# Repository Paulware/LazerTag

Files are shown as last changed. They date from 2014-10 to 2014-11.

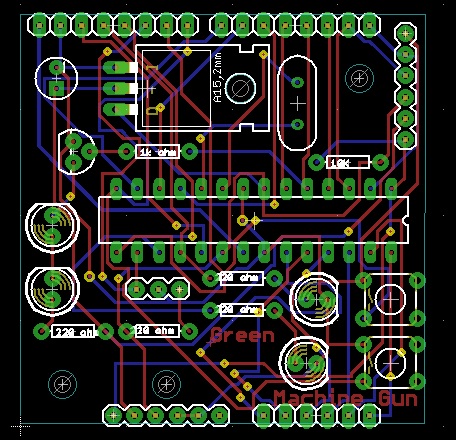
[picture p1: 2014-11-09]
ShieldHardware/IRRxTx.jpg

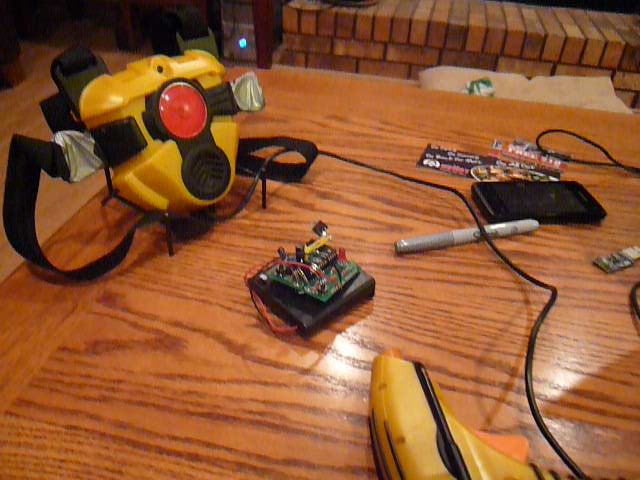
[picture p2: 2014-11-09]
LazerTag/P1040091.JPG

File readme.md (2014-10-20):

<H3>Hardware</H3>
<ul>
<li> Arduino Shield with IR Transmit and receive</li>
<ul>
<li>Fritzing Diagrama</li>
<li>Eagle schematic and board</li>
<li>Gerber .zip file (Iteadstudio.com) can create pcb</li>
</ul>
</ul>
<H3>Software</H3>
<ul>
<li>LazerTag.ino sketch to send and receive pulses</li>
<li>libraries</li>
<ul>
<li>IR - Basic IR Sampling library</li>
<li>IRLazer - Lazer tab receive and transmit</li>
</ul>
</ul>
<hr>
Future:
  Add :
    IR "grenades"
    Capture the ir "flag"

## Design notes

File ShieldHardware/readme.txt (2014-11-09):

11/3/2014
    Red LED should be marked because infra-red emitters also look like leds.
    IR Tx leds should be rotated 90 degrees so they can be bent without shorting
    3V regulator LD33V has incorrect part in schematic.  Its a sparkfun part.
    Pinout was incorrectly for LM7805 regulator 
    Ready for reorder (not urgent)
    To assemble, shift LD part one pin, unused pin goes to first pin(VCC)
    
11/6/2014
    16 mhz clock and 10k resistor moved to top of pcb so that the unit 
    can be glued to a flat surface.  Added standoff holes .
    
11/7/2014
    Added 8 and 6 pin headers in case this could be used like a DIY Arduino.  Moved
    standoffs more to the corner.

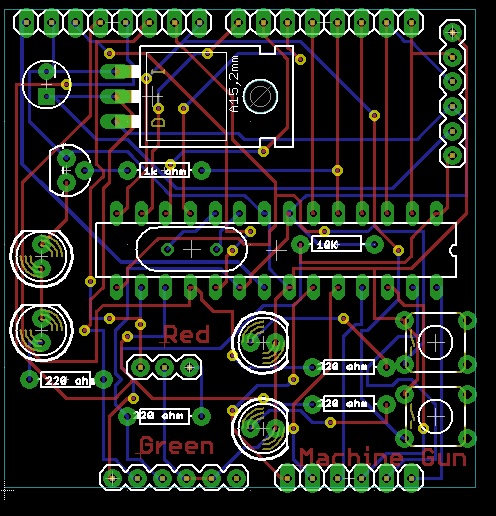
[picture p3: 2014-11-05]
LazerTag/IRRxTx.jpg

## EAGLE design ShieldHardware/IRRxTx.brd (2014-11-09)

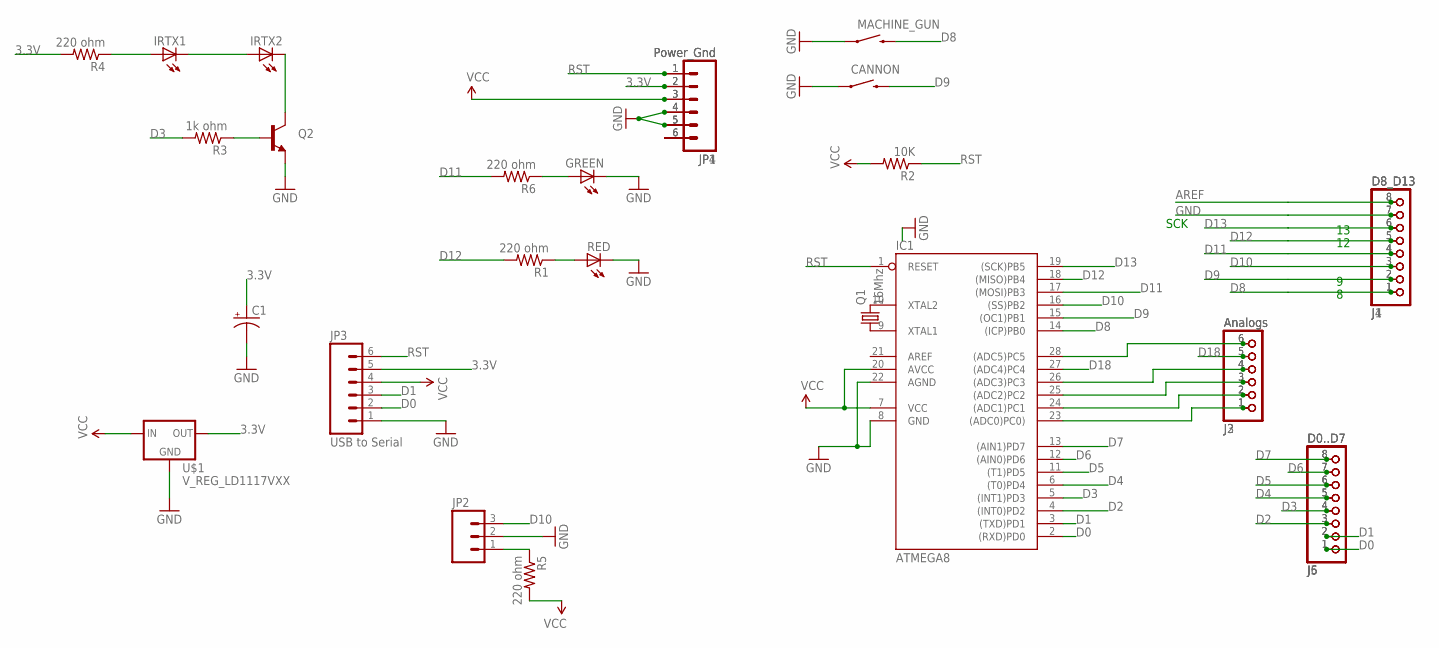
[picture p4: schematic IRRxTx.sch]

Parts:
C1: CAP_POLPTH2; CPOL-RADIAL-10UF-25V
CANNON: SWITCH-MOMENTARY-2PTH; TACTILE-PTH
GREEN: LED5MM
IC1: ATMEGA8; DIL28-3
IRTX1, IRTX2: LED5MM
J1, J4: D8_D13; 1X08
J2, J3: Analogs; 1X06
J5, J6: D0..D7; 1X08
JP1, JP4: Power_Gnd; 1X06
JP2: M03PTH; 1X03
JP3: USB to Serial; 1X06
MACHINE_GUN: SWITCH-MOMENTARY-2PTH; TACTILE-PTH
Q1: 16Mhz; HC49US
Q2: TRANSISTOR_NPNTO92; TO-92
R1, R4, R5, R6: 220 ohm; AXIAL-0.3
R2: 10K; AXIAL-0.3
R3: 1k ohm; AXIAL-0.3
RED: LED5MM
U$1: V_REG_LD1117VXX; 78XXL

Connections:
3.3V: C1.1 (+), JP1.2, JP3.5, JP4.2, R4.P$2 (2), U$1.GND (OUT)
AREF: IC1.21 (AREF), J1.8, J4.8
D0: IC1.2 ((RXD)PD0), J5.1, J6.1, JP3.2
D1: IC1.3 ((TXD)PD1), J5.2, J6.2, JP3.3
D2: IC1.4 ((INT0)PD2), J5.3, J6.3
D3: IC1.5 ((INT1)PD3), J5.4, J6.4, R3.P$2 (2)
D4: IC1.6 ((T0)PD4), J5.5, J6.5
D5: IC1.11 ((T1)PD5), J5.6, J6.6
D6: IC1.12 ((AIN0)PD6), J5.7, J6.7
D7: IC1.13 ((AIN1)PD7), J5.8, J6.8
D8: IC1.14 ((ICP)PB0), J1.1, J4.1, MACHINE_GUN.3 (2)
D9: CANNON.3 (2), IC1.15 ((OC1)PB1), J1.2, J4.2
D10: IC1.16 ((SS)PB2), J1.3, J4.3, JP2.3
D11: IC1.17 ((MOSI)PB3), J1.4, J4.4, R6.P$2 (2)
D12: IC1.18 ((MISO)PB4), J1.5, J4.5, R1.P$2 (2)
D13: IC1.19 ((SCK)PB5), J1.6, J4.6
D18: IC1.27 ((ADC4)PC4), J2.5, J3.5
GND: C1.2 (-), CANNON.1, GREEN.K (C), IC1.8 (GND), IC1.22 (AGND), J1.7, J4.7, JP1.4, JP1.5, JP2.2, JP3.1, JP4.4, JP4.5, MACHINE_GUN.1, Q2.1 (E), RED.K (C), U$1.IN (GND)
unnamed: IC1.10 (XTAL2), Q1.2
unnamed: IC1.9 (XTAL1), Q1.1
unnamed: R1.P$1 (1), RED.A
unnamed: Q2.2 (B), R3.P$1 (1)
unnamed: IRTX2.K (C), Q2.3 (C)
unnamed: IRTX1.K (C), IRTX2.A
unnamed: IRTX1.A, R4.P$1 (1)
unnamed: JP2.1, R5.P$1 (1)
unnamed: GREEN.A, R6.P$1 (1)
unnamed: JP1.6, JP4.6
unnamed: IC1.23 ((ADC0)PC0)), J2.1, J3.1
unnamed: IC1.24 ((ADC1)PC1), J2.2, J3.2
unnamed: IC1.25 ((ADC2)PC2), J2.3, J3.3
unnamed: IC1.26 ((ADC3)PC3), J2.4, J3.4
unnamed: IC1.28 ((ADC5)PC5), J2.6, J3.6
RST: IC1.1 (RESET), JP1.1, JP3.6, JP4.1, R2.P$1 (1)
VCC: IC1.7 (VCC), IC1.20 (AVCC), JP1.3, JP3.4, JP4.3, R2.P$2 (2), R5.P$2 (2), U$1.OUT (IN)

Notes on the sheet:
SCK

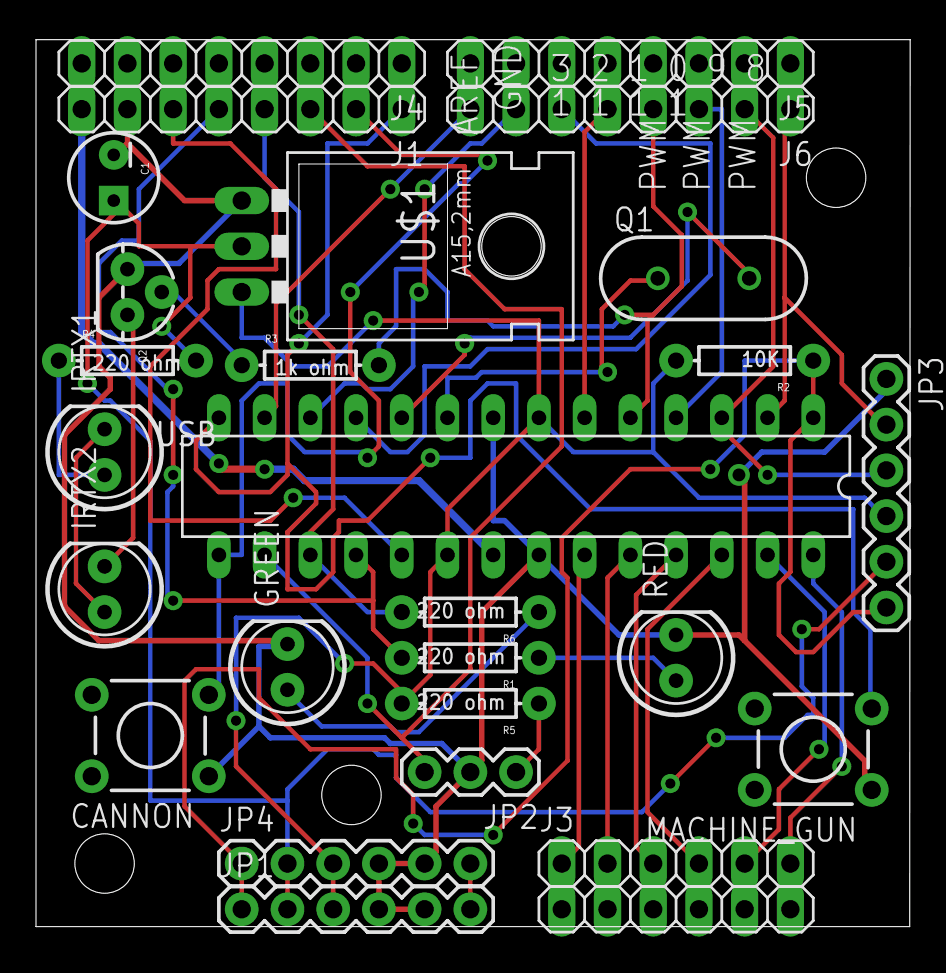
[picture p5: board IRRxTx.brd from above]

Board: 2 copper layers, 48.6 x 49.3 mm, 30 parts (0 on the bottom side), 35 nets.

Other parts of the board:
U$2, U$3, U$4: STAND-OFF

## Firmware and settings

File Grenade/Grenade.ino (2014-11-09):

#include <TimerOne.h>
#include <IR.h>
#include <IRLazer.h>
#include <MemoryFree.h>

#define IRRECEIVEPIN 10
#define IRTRANSMIT 3
#define REPAIRROBOT false

IRLazer ir (IRRECEIVEPIN, IRTRANSMIT, &Timer1, REPAIRROBOT);
unsigned long timeout = 0;
unsigned long fireTimeout = 0;
unsigned long ceaseFire = 0;

void setup() {
  ir.init(); 
  
  pinMode (5,INPUT);  // Switch input
  pinMode (3,OUTPUT); // IR Tx
  pinMode (6,OUTPUT); // Sound module go
  digitalWrite (5,1); // pull-up internal resistor
  Serial.begin (115200);
  Serial.println ( "Ready" );
}

void fireLazer () {
  ir.fireType = 0; // Normal gun fire shot
  Serial.println ( "Calling fireAll" );
  ir.fireAll ();
}

void explode() {
  digitalWrite (6,1);
  delay (400);
  digitalWrite (6,0);
}
int lastButton = 1;
void loop () {
  int value = digitalRead (5);
  if (value != lastButton) {
    lastButton = value;
    if (value == 0)
    {
       Serial.println ( "button pushed" );
       fireTimeout = millis() + 1000;
       ceaseFire = millis() + 6000;  // Fire for six seconds
       explode();
    }   
  }
  
  if (fireTimeout > 0) {
    if (millis() > fireTimeout) {
      fireLazer();      
      fireTimeout = millis() + 400;
    }
    if (millis() > ceaseFire) {
      ceaseFire = 0;
      fireTimeout = 0;
    }
  }
}

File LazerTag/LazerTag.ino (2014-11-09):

#include <TimerOne.h>
#include <IR.h>
#include <IRLazer.h>
#include <MemoryFree.h>

#define IRRECEIVEPIN 10
#define IRTRANSMIT 3
#define REPAIRROBOT false
#define REDLED 12
#define GREENLED 11
#define CANNONBUTTON 9
#define GUNBUTTON 8

IRLazer ir (IRRECEIVEPIN, IRTRANSMIT, &Timer1, REPAIRROBOT);
unsigned long redTimeout = 0;
unsigned long greenTimeout = 0;
unsigned long fireTimeout = 0;
boolean irEnable = true;
unsigned long irTimeout = 0;

void setup()
{
  ir.init(); 
  Timer1.initialize (25);
  Timer1.attachInterrupt(callback,25);  
  
  pinMode (REDLED,OUTPUT);
  pinMode (GREENLED,OUTPUT);
  
  // Button for Main Cannon
  pinMode (CANNONBUTTON,INPUT);
  digitalWrite (CANNONBUTTON,1); // Internal pull up set
  
  // Button for Machine Gun
  pinMode (GUNBUTTON,INPUT);
  digitalWrite (GUNBUTTON,1); // Internal pull up set
  
  Serial.begin (115200);
  Serial.println ( "Ready" );
  digitalWrite (REDLED,1);
  digitalWrite (GREENLED,1);
  redTimeout = millis() + 1000;
  greenTimeout = millis() + 1000;
  
  Serial.print ( "Free Memory: " );
  Serial.println ( freeMemory() );
}

void callback() // Timer1 is set to 25 microsecond to balance PWM output
{
  static bool skip = false;
  if (irEnable) {
    skip = !skip;
    if (!skip)
      ir.callback();
  }  
}

void fireLazer (int which) {
  irEnable = false;
  ir.fireType = which; // 0 = normal pulse, 1 = heal
  ir.fireAll ();
  digitalWrite (GREENLED,1);
  greenTimeout = millis() + 500;
  irEnable = true;
}

int lastCannon = 0;
int lastGun = 0;
void loop () {
  int value = digitalRead (CANNONBUTTON);
  if (value != lastCannon)
  {
    lastCannon = value;
    if (!value) {
       fireLazer (0);
       Serial.println ( "Fire lazer gun" );
       delay (300);
    }
  }
  
  value = digitalRead (GUNBUTTON);
  if (value != lastGun)
  {
    lastGun = value;
    if (!value) {
       fireLazer (1);
       Serial.println ( "Heal" );
       delay (300);
    }
  }

  int irDetected = ir.decodeBits (33, true, false);
    
  static int redGreen = 0;
  
  if (redTimeout > 0)
     if (millis() > redTimeout) {
        digitalWrite (REDLED, 0);
        redTimeout = 0;
     }  
    
  if (greenTimeout > 0) 
     if (millis() > greenTimeout) {
       digitalWrite (GREENLED, 0);
       greenTimeout = 0;
     }  
  
  if (irDetected ==  -1) {
     Serial.println ( "Got something" );
     digitalWrite (REDLED, 1);
     redTimeout = millis() + 500;
     irEnable = false;
     ir.resetIR(); 
     irEnable = true;  
  }
  else if (millis() > irTimeout) {
    ir.resetIR();
    irTimeout = millis() + 1000;
  }
}

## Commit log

2014-10-19 Initial Creation
    Add Fritzing file, eagle schematic, sketches and libraries
    [IRRxTx.brd, IRRxTx.fzz, IRRxTx.sch]
2014-10-20 v0.03
    Added IRLazer library directory
    Can now shoot and heal (reset)
    [LazerTag.ino]
2014-10-20 v0.04
    Modified Readme file, organized file directories
    [IRRxTx.brd, IRRxTx.fzz, IRRxTx.sch]
2014-11-05 v0.06
    Updated Schematic
    [IRRxTx.fzz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]
2014-11-09 v.0.07
    Added Grenade
    [IRRxTx.brd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]
